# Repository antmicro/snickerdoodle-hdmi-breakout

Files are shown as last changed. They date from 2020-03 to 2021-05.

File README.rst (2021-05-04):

===========================
Snickerdoodle HDMI breakout
===========================

Copyright (c) 2020 Antmicro <`www.antmicro.com <https://www.antmicro.com>`_>

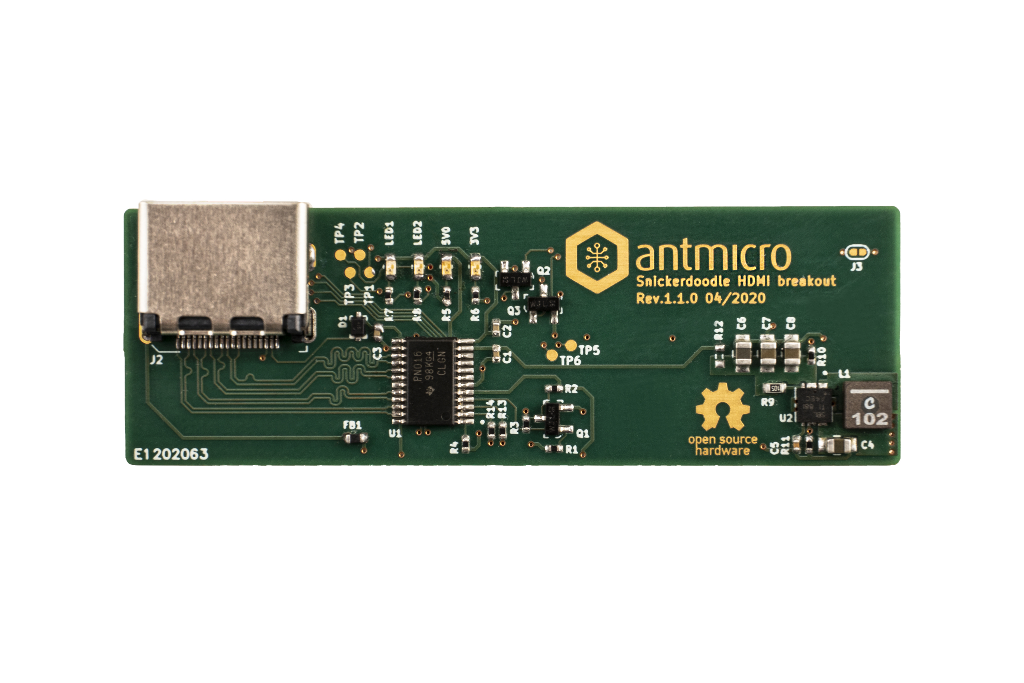
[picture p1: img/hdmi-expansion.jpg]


This repository contains open hardware design files for an expansion board compatible with `krtkl's breakyBreaky carrier board <https://www.xilinx.com/products/boards-and-kits/1-gex6t6.html>`_ for the `snickerdoodle <https://krtkl.com/snickerdoodle/>`_ prototyping platform.

The design files were created in KiCad.

The expansion board breaks out the HDMI interface on a regular HDMI connector.
The TMDS data lanes from this connector are connected to the FPGA fabric in the Zynq 7000 on the snickerdoodle module.
The expansion board should be connected to the ``JB2`` pinhead available on the breakyBreaky board. It is compatible with breakyBreaky rev.3.0 and rev.4.0 (make sure pin 1 indicators align).

Dimensions and layout
=====================

The image below shows the HDMI Expansion board's dimensions and layout.

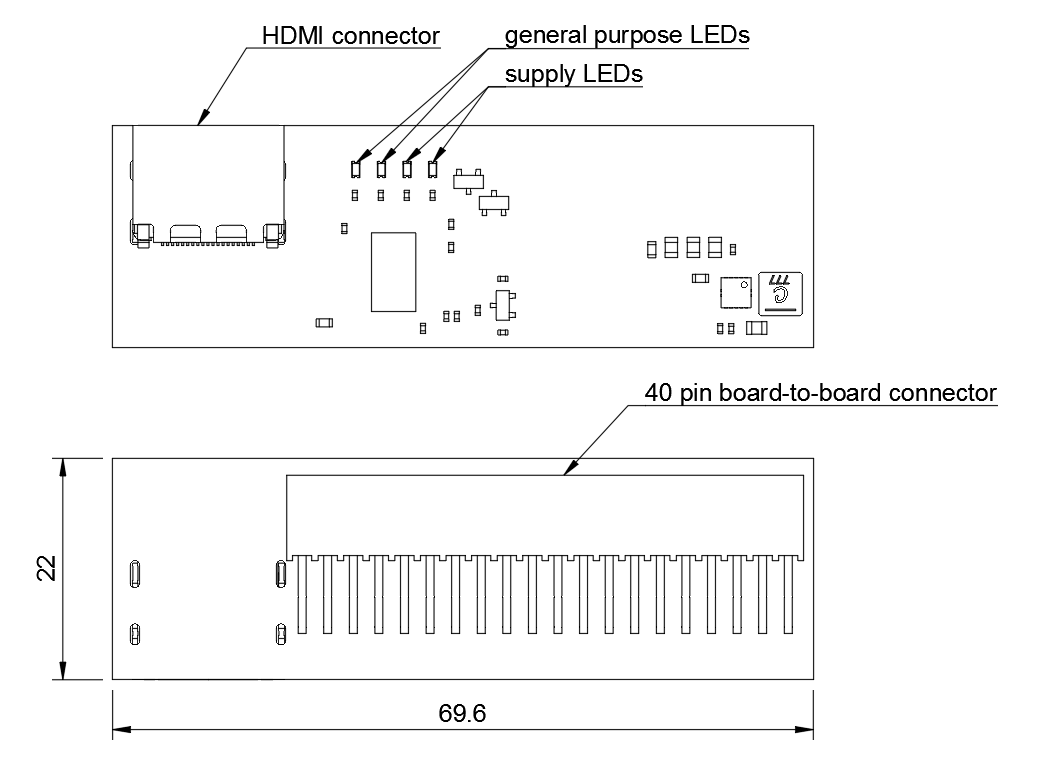
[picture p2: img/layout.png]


For more information regarding electrical connections please refer to the schematic sheets and compare them against the `offcial documentation <https://github.com/krtkl/open-source-schematics>`_ of breakyBreaky and snickerdoodle module.

License
=======

`Apache-2.0 <LICENSE>`_

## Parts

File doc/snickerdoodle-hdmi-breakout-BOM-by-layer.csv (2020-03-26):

Reference | Quantity | Value | Footprint | Manufacturer | MPN | Layer
3V3 5V0 LED1 LED2 | 4 | KP-1608CGCK | LED_0603 | KINGBRIGHT | KP-1608CGCK | Top
C1 C2 C3 | 3 | C_100n_0402_6V3 | 0402-cap | Walsin | 0402X104K6R3CT | Top
C4 | 1 | C_22u_0805 | 0805-cap | MULTICOMP | MC0805X226M6R3CT | Top
C5 | 1 | C_10n_0402 | 0402-cap | AVX | 04025G103ZAT2A | Top
C6 C7 C8 | 3 | C_22u_0805_10V | 0805-cap | AVX | 0805ZD226MAT2A | Top
D1 | 1 | 1N4148WS | SOD-323F | ON Semiconductor | 1N4148WS | Top
FB1 | 1 | BLM18PG121SN1D | 0603 | Murata Electronics North America | BLM18PG121SN1D | Top
J2 | 1 | 685119134923 | HDMI_A_Female_685119134923 | Amphenol | 685119134923 | Top
L1 | 1 | XFL4020-102MEB | XFL4020-102MEB | Coilcraft | XFL4020-102MEB | Top
Q2 Q3 | 2 | BSS138AKA | SOT-23-3 | ON Semiconductor | BSS138AKA | Top
R10 R13 R14 R3 | 4 | R_0R_0402 | 0402-res | PANASONIC | ERJ2GE0R00X | Top
R11 | 1 | R_100k_0402 | 0402-res | VISHAY | CRCW0402100KFKEDHP | Top
R12 | 1 | R_0R_0603 | 0603-res | BOURNS | CR0603-J/-000ELF | Top
R4 | 1 | R_10k_0402 | 0402-res | VISHAY | CRCW040210K0FKEDHP | Top
R5 | 1 | R_470R_0402 | 0402-res | VISHAY | CRCW0402470RFKED. | Top
R6 R7 R8 | 3 | R_330R_0402 | 0402-res | MULTICOMP | MCMR04X3300FTL | Top
R9 | 1 | R_1M_0603 | 0603-res | BOURNS | CR0603-JW-105GLF | Top
U1 | 1 | TPD12S016PWR | TPD12S016PWR | Texas Instruments | TPD12S016PWR | Top
U2 | 1 | TPS61232DRCT | VSON-10-1EP_3x3mm | Texas Instruments | TPS61232DRCT | Top
J1 | 1 | SMH-120-02-T-D | SMH-120-02-T-D | SAMTEC | SMH-120-02-T-D | Bottom
Q1 | 1 | BSS138AKA | SOT-23-3 | ON Semiconductor | BSS138AKA | DNP
R1 R2 | 2 | R_10k_0402 | 0402-res | VISHAY | CRCW040210K0FKEDHP | DNP
J3 | 1 | solder_jumper | SolderJumper-0.6x1.4mm | None | None | Virtual
N1 | 1 | oshw_logo | oshw-logo |  |  | Virtual
N2 | 1 | antmicro_logo | antmicro-logo |  |  | Virtual
TP1 TP2 TP3 TP4 TP5 TP6 | 6 | TP_SMD1MM | Testpoint_smd_1mm |  |  | Virtual

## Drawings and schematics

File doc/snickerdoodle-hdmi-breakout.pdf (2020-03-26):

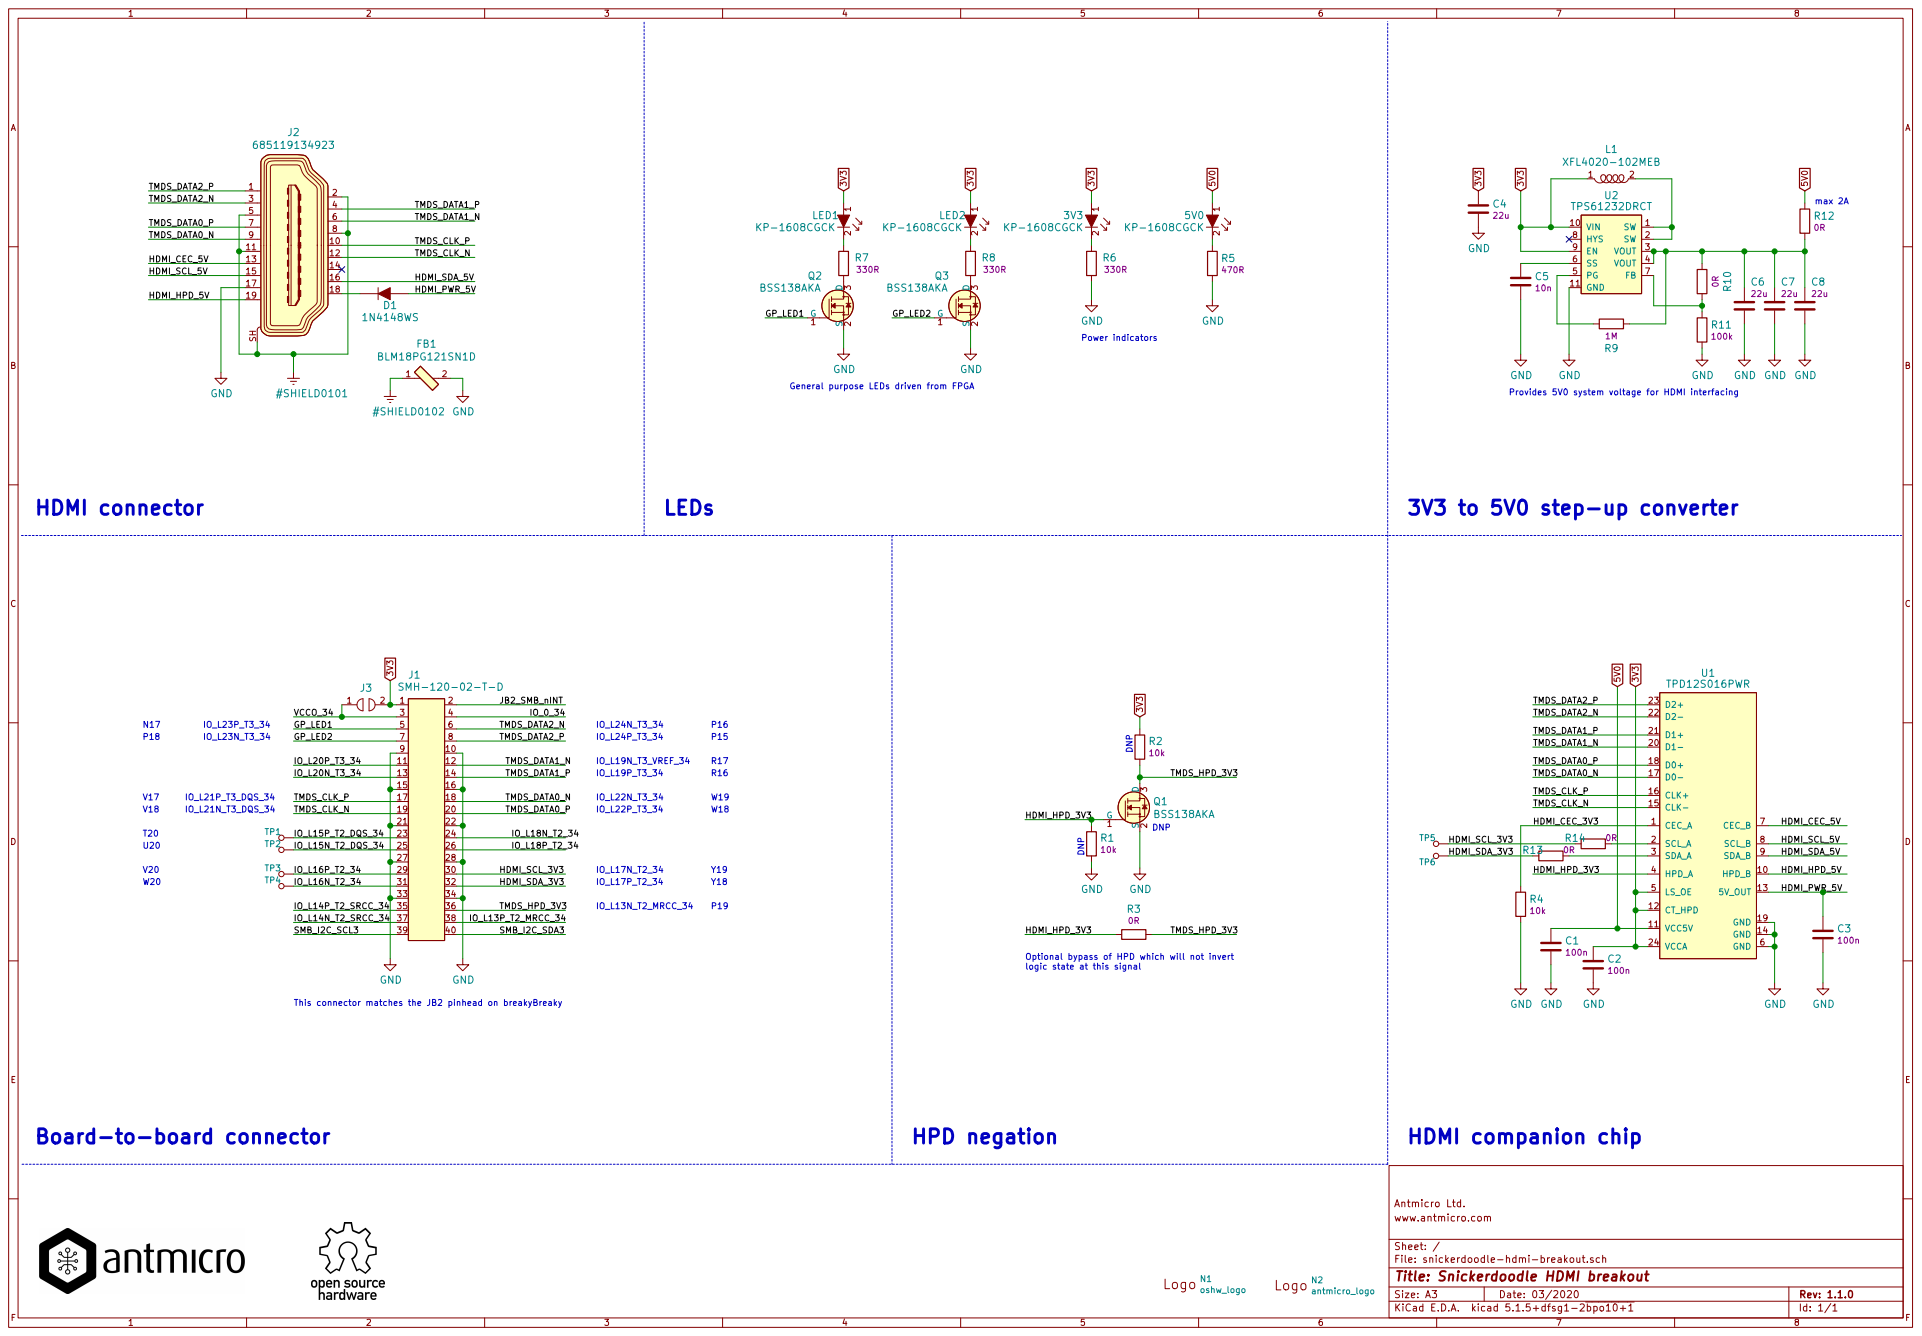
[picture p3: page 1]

General purpose LEDs driven from FPGA

3V3 to 5V0 step-up converter

Y18 P18 Board-to-board connector

logic state at this signal

This connector matches the JB2 pinhead on breakyBreaky

Antmicro Ltd.
Id: 1/1 Title: Snickerdoodle HDMI breakout File: snickerdoodle-hdmi-breakout.sch Sheet: / www.antmicro.com

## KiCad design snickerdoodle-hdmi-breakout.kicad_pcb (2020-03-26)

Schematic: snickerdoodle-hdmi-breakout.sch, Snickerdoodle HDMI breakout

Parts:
3V3, 5V0: KP-1608CGCK; LED_0603; MPN KP-1608CGCK
C1, C2, C3: C_100n_0402_6V3; 0402-cap; MPN 0402X104K6R3CT
C4: C_22u_0805; 0805-cap; MPN MC0805X226M6R3CT
C5: C_10n_0402; 0402-cap; MPN 04025G103ZAT2A
C6, C7, C8: C_22u_0805_10V; 0805-cap; MPN 0805ZD226MAT2A
D1: 1N4148WS; SOD-323F; MPN 1N4148WS
FB1: BLM18PG121SN1D; 0603-res; MPN BLM18PG121SN1D
J1: SMH-120-02-T-D; MPN SMH-120-02-T-D
J2: 685119134923; HDMI_A_Female_685119134923; MPN 685119134923
J3: solder_jumper; SolderJumper-0.6x1.4mm; MPN None
L1: XFL4020-102MEB; MPN XFL4020-102MEB
LED1, LED2: KP-1608CGCK; LED_0603; MPN KP-1608CGCK
N1: oshw_logo; oshw-logo
N2: antmicro_logo; antmicro-logo_scaled_20mm
Q1, Q2, Q3: BSS138AKA; SOT-23-3; MPN BSS138AKA
R1, R2, R4: R_10k_0402; 0402-res; MPN CRCW040210K0FKEDHP
R3, R10, R13, R14: R_0R_0402; 0402-res; MPN ERJ2GE0R00X
R5: R_470R_0402; 0402-res; MPN CRCW0402470RFKED.
R6, R7, R8: R_330R_0402; 0402-res; MPN MCMR04X3300FTL
R9: R_1M_0603; 0603-res; MPN CR0603-JW-105GLF
R11: R_100k_0402; 0402-res; MPN CRCW0402100KFKEDHP
R12: R_0R_0603; 0603-res; MPN CR0603-J/-000ELF
TP1, TP2, TP3, TP4, TP5, TP6: TP_SMD1MM; Testpoint_smd_1mm
U1: TPD12S016PWR; MPN TPD12S016PWR
U2: TPS61232DRCT; VSON-10-1EP_3x3mm; MPN TPS61232DRCT

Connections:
3V3: 3V3.1, C2.2, C4.1, J1.1, J3.2, L1.1, LED1.1, LED2.1, R2.2, U1.5 (LS_OE), U1.12 (CT_HPD), U1.24 (VCCA), U2.9 (EN), U2.10 (VIN)
5V0: 5V0.1, C1.2, R12.1, U1.11 (VCC5V)
/GP_LED1: J1.5, Q2.1 (G)
/GP_LED2: J1.7, Q3.1 (G)
/HDMI_CEC_3V3: R4.1, U1.1 (CEC_A)
/HDMI_CEC_5V: J2.13, U1.7 (CEC_B)
/HDMI_HPD_3V3: Q1.1 (G), R1.2, R3.1, U1.4 (HPD_A)
/HDMI_HPD_5V: J2.19, U1.10 (HPD_B)
/HDMI_PWR_5V: C3.2, D1.A, U1.13 (5V_OUT)
/HDMI_SCL_3V3: J1.30, R14.1, TP5.1
/HDMI_SCL_5V: J2.15, U1.8 (SCL_B)
/HDMI_SDA_3V3: J1.32, R13.1, TP6.1
/HDMI_SDA_5V: J2.16, U1.9 (SDA_B)
/IO_0_34: J1.4
/IO_L13P_T2_MRCC_34: J1.38
/IO_L14N_T2_SRCC_34: J1.37
/IO_L14P_T2_SRCC_34: J1.35
/IO_L15N_T2_DQS_34: J1.25, TP2.1
/IO_L15P_T2_DQS_34: J1.23, TP1.1
/IO_L16N_T2_34: J1.31, TP4.1
/IO_L16P_T2_34: J1.29, TP3.1
/IO_L18N_T2_34: J1.24
/IO_L18P_T2_34: J1.26
/IO_L20N_T3_34: J1.13
/IO_L20P_T3_34: J1.11
/JB2_SMB_nINT: J1.2
/SMB_I2C_SCL3: J1.39
/SMB_I2C_SDA3: J1.40
/TMDS_CLK_N: J1.19, J2.12, U1.15 (CLK-)
/TMDS_CLK_P: J1.17, J2.10, U1.16 (CLK+)
/TMDS_DATA0_N: J1.18, J2.9, U1.17 (D0-)
/TMDS_DATA0_P: J1.20, J2.7, U1.18 (D0+)
/TMDS_DATA1_N: J1.12, J2.6, U1.20 (D1-)
/TMDS_DATA1_P: J1.14, J2.4, U1.21 (D1+)
/TMDS_DATA2_N: J1.6, J2.3, U1.22 (D2-)
/TMDS_DATA2_P: J1.8, J2.1, U1.23 (D2+)
/TMDS_HPD_3V3: J1.36, Q1.3 (D), R2.1, R3.2
/VCCO_34: J1.3, J3.1
Earth: FB1.1, J2.2, J2.5, J2.8, J2.11, J2.SH
GND: C1.1, C2.1, C3.1, C4.2, C5.2, C6.2, C7.2, C8.2, FB1.2, J1.9, J1.10, J1.15, J1.16, J1.21, J1.22, J1.27, J1.28, J1.33, J1.34, J2.17, Q1.2 (S), Q2.2 (S), Q3.2 (S), R1.1, R4.2, R5.2, R6.2, R11.2, U1.6 (GND), U1.14 (GND), U1.19 (GND), U2.11 (GND)
unnamed: 3V3.2, R6.1
unnamed: 5V0.2, R5.1
unnamed: C5.1, U2.6 (SS)
unnamed: C6.1, C7.1, C8.1, R9.2, R10.1, R12.2, U2.3 (VOUT), U2.4 (VOUT)
unnamed: D1.K, J2.18
unnamed: L1.2, U2.1 (SW), U2.2 (SW)
unnamed: LED1.2, R7.1
unnamed: LED2.2, R8.1
unnamed: Q2.3 (D), R7.2
unnamed: Q3.3 (D), R8.2
unnamed: R9.1, U2.5 (PG)
unnamed: R10.2, R11.1, U2.7 (FB)
unnamed: R13.2, U1.3 (SDA_A)
unnamed: R14.2, U1.2 (SCL_A)

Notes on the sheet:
IO_L24N_T3_34
IO_L24P_T3_34
IO_L19N_T3_VREF_34
IO_L19P_T3_34
IO_L22N_T3_34
IO_L22P_T3_34
IO_L17N_T2_34
IO_L17P_T2_34
IO_L13N_T2_MRCC_34
IO_L23P_T3_34
IO_L23N_T3_34
Board-to-board connector
3V3 to 5V0 step-up converter
HDMI companion chip
P16
P15
R17
R16
W19
W18
Y19
Y18
P19
P18
N17
Optional bypass of HPD which will not invert logic state at this signal
General purpose LEDs driven from FPGA
Power indicators
Provides 5V0 system voltage for HDMI interfacing
max 2A
This connector matches the JB2 pinhead on breakyBreaky
HDMI connector
IO_L21P_T3_DQS_34
IO_L21N_T3_DQS_34
V17
V18
LEDs
HPD negation
T20
U20

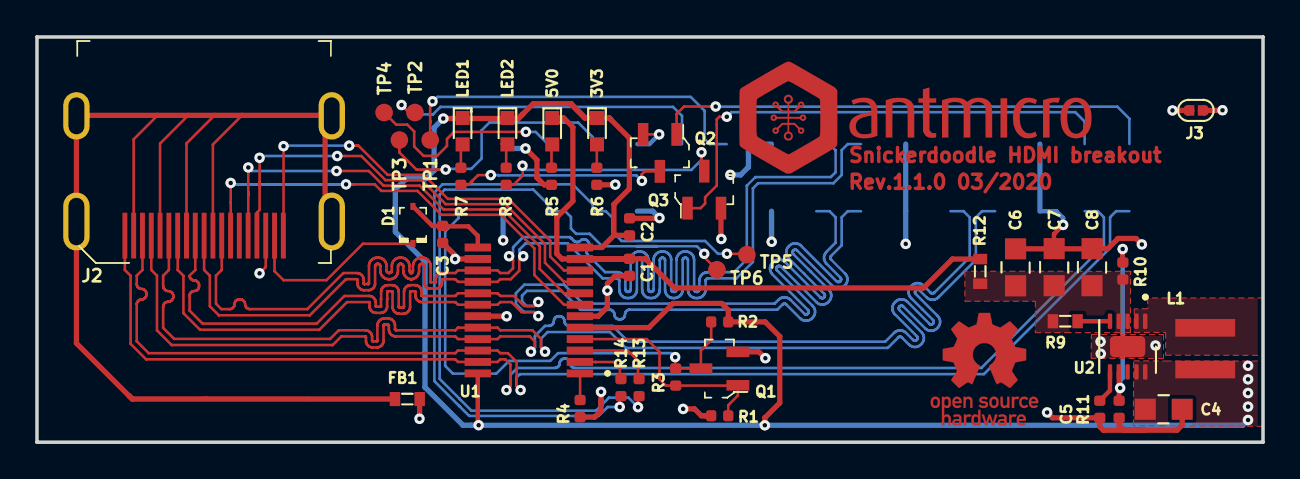
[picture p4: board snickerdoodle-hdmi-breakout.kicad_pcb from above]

Board: 4 copper layers, 69.6 x 23.0 mm, 45 parts (1 on the bottom side), 43 nets.

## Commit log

2020-03-18 Added project files, added dxf outline to PCB, initial work on schematics
    [krtkl-breakybreaky-hdmi-expansion.kicad_pcb, krtkl-breakybreaky-hdmi-expansion.sch]
2020-03-18 Finished schematics, added components to PCB
    [krtkl-breakybreaky-hdmi-expansion.kicad_pcb, krtkl-breakybreaky-hdmi-expansion.sch]
2020-03-18 Defined component placement and board stackup
    [krtkl-breakybreaky-hdmi-expansion.kicad_pcb]
2020-03-18 Added TODOs and some remarks
    [krtkl-breakybreaky-hdmi-expansion.sch]
2020-03-18 Resolved TODOs, cleaned up the schematic layout
    [krtkl-breakybreaky-hdmi-expansion.sch]
2020-03-18 Changed CLK connection on 40-pin connector
    [krtkl-breakybreaky-hdmi-expansion.sch]
2020-03-18 Fixed symbol for J2 on schematics
    [krtkl-breakybreaky-hdmi-expansion.sch]
2020-03-18 Schematic cleanup
    [krtkl-breakybreaky-hdmi-expansion.sch]
2020-03-18 PCB routed with matched length of diff-pairs
    [krtkl-breakybreaky-hdmi-expansion.kicad_pcb]
2020-03-18 Finished routing, minor footprint fixes
    [krtkl-breakybreaky-hdmi-expansion.kicad_pcb, krtkl-breakybreaky-hdmi-expansion.sch]
2020-03-18 Added logotypes
    [krtkl-breakybreaky-hdmi-expansion.sch]
2020-03-18 Added testpads, 0R on EDID and board branding to PCB
    [krtkl-breakybreaky-hdmi-expansion.kicad_pcb, krtkl-breakybreaky-hdmi-expansion.sch]
2020-03-18 DRC resolved
    [krtkl-breakybreaky-hdmi-expansion-B_Cu.gbr, krtkl-breakybreaky-hdmi-expansion-B_Mask.gbr, krtkl-breakybreaky-hdmi-expansion-B_Paste.gbr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]
2020-03-18 Updated documentation, added README and LICENSE
    [krtkl-breakybreaky-hdmi-expansion.kicad_pcb, krtkl-breakybreaky-hdmi-expansion.sch]
2020-03-18 Updated naming convention
    [krtkl-breakybreaky-hdmi-expansion-B_Cu.gbr, krtkl-breakybreaky-hdmi-expansion-B_Mask.gbr, krtkl-breakybreaky-hdmi-expansion-B_Paste.gbr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]
2020-03-18 Updated component library
    [snickerdoodle-hdmi-breakout.kicad_pcb, snickerdoodle-hdmi-breakout.sch]
2020-03-18 Release 1.0.1
    [snickerdoodle-hdmi-breakout-B_Cu.gbr, snickerdoodle-hdmi-breakout-B_Mask.gbr, snickerdoodle-hdmi-breakout-B_Paste.gbr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]
2020-03-18 Added BOM files
    [snickerdoodle-hdmi-breakout-BOM-by-layer.csv, snickerdoodle-hdmi-breakout-BOM-populated.csv]
2020-03-18 Updated Manufacturer for HDMI connector
    [snickerdoodle-hdmi-breakout-BOM-by-layer.csv, snickerdoodle-hdmi-breakout-BOM-populated.csv, snickerdoodle-hdmi-breakout.sch]
2020-03-24 Prepared files for revision 1.1.0 - rotated HDMI connector, changed PCB size
    [snickerdoodle-hdmi-breakout-BOM-by-layer.csv, snickerdoodle-hdmi-breakout-BOM-populated.csv, snickerdoodle-hdmi-breakout.kicad_pcb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]
2020-03-24 Added documentation for release 1.1.0
    [snickerdoodle-hdmi-breakout-B_Cu.gbr, snickerdoodle-hdmi-breakout-B_Mask.gbr, snickerdoodle-hdmi-breakout-B_Paste.gbr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]
2020-03-26 Changed R10, re-generated documentation
    [snickerdoodle-hdmi-breakout-BOM-by-layer.csv, snickerdoodle-hdmi-breakout-BOM-populated.csv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]
